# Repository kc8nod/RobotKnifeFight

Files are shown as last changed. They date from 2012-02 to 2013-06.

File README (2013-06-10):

Robot Knife Fight v0.10 (master)

Robot Knife Fight is a game that uses Python 2.7+, Arduino v1.0.3+, OpenCV 2.4.5+, and zbar 0.10 to scan a video source for QR codes for robot positions, if the robot is alive, and the arena's edges.  The position is sent out via an Arduino transmitter using a Virtual Wire 433Mhz Radio to each Arduino robot.  Each robot has a balloon covering it's DEAD symbol that also holds down it's power button.  When it's balloon pops the robot turns off.

The game is simple.  Each robot tries to pop the balloon of the other robots and be the last alive.

We are currently in Beta stages.  Positioning works but could use some optimizations.  The 433Mhz Radio that each Arduino uses to receive the position of itself and the other robots could use review.  The QR scanning with zbar could be set to focus on just the arena area.  Setting zbar to increase the number of scanning passes on certain areas of the image is also possible.

3d_model/                           #Sketchup design files for the robot.
code/arena/                         #Python script that scans the video for QR codes
                                    # and sends commands to the transmitter.
code/example_bot_attack /           #Arduino robot code that drives straight towards
                                    # the nearest living robot.
code/example_bot_patrol/            #Arduino robot code patrols between 4 points.
code/libraries/                     #Libraries you will need to copy to your 
                                    # 'arduino/libraries' folder.
code/rkf_xmit/                      #Arduino code for the transmitter.
code/serial_drivable_bot/           #Arduino robot code that's drivable via serial
                                    # commands (Xbee, Bluetooth, etc.)
code/serial_keyboard_controller/    #Processing script to drive up to 2 bots via
                                    # serial connections.
harware/                            #Shield Schematic for Virtual Wire Radio, servo
                                    # connectors, switch connectors, and a serial
                                    # module (Bluetooth Mate, FTDI pinout).
lasercut/                           #The exported DXF file of the Flat_Pack.skp for
                                    # lasercutting the robot.
qrcodes/                            #PNG files of the QR codes for the arena corners
                                    # (A###-C#), Robot symbols (http://###), and the
                                    # robot death symbols (DEAD###).

We currently suggest print sizes of 5.25"x5.25" for arena corners and 4.25"x4.25" for robot symbols.

Check http://i3detroit.com for events.

https://github.com/SWiT/RobotKnifeFight
https://github.com/kc8nod/RobotKnifeFight

https://github.com/SWiT/RobotFightClubArena

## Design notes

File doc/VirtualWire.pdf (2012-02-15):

February 7, 2012

### 1 of 13

# VirtualWire

Copyright (C) 2008-2011
Mike McCauley

Documentation for the VirtualWire 1.9 communications library for Arduino.

### 1.0 Introduction

Arduino is a low cost microcontroller with Open Source hardware, see http://www.arduino.cc. VirtualWire is a communications library for Arduino that allows multiple Arduino’s to communicate using low-cost RF transmitters and receivers.

The document describes the VirtualWire library and how to install and use it.

You can also find online help and disussion at

http://groups.google.com/group/virtualwire

### 2.0 Overview

VirtualWire is an Arduino library that provides features to send short messages, without addressing, retransmit or acknowledgment, a bit like UDP over wireless, using ASK (amplitude shift keying). Supports a number of inexpensive radio transmitters and receivers. All that is required is transmit data, receive data and (for transmitters, optionally) a PTT transmitter enable.

It is intended to be compatible with the RF Monolithics (www.rfm.com) Virtual Wire protocol, but this has not been tested.

Does not use the Arduino UART. Messages are sent with a training preamble, message length and checksum. Messages are sent with 4-to-6 bit encoding for good DC balance, and a CRC checksum for message integrity.

Overview

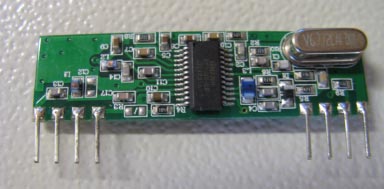
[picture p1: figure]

2 of 13 | VirtualWire

Why not just use the Arduino UART connected directly to the transmitter/receiver? As discussed in the RFM documentation, ASK receivers require a burst of training pulses to synchronize the transmitter and receiver, and also requires good balance between 0s and 1s in the message stream in order to maintain the DC balance of the message. UARTs do not provide these. They work a bit with ASK wireless, but not as well as this code.

2.1 Supported hardware.
A range of communications hardware is supported. The ones listed blow are available in common retail outlets in Australian and other countries for under $10 per unit. Many other modules may also work with this software.

Runs on ATmega8/168 (Arduino Diecimila etc) and ATmega328 and possibly others.

### 2.2 Receivers

- RX-B1 (433.92MHz) (also known as ST-RX04-ASK)
FIGURE 1. | RX-B1

Details at http://www.summitek.com.tw/ST_SPEC/ST-RX04-ASK.pdf

### 2.3 Transmitters:

- TX-C1 (433.92MHz)

Overview

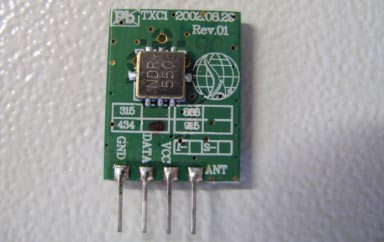
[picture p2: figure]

VirtualWire | 3 of 13
FIGURE 2. | TX-C1

Details at http://www.tato.ind.br/files/TX-C1.pdf

### 2.4 Transceivers:

- DR3100 (433.92MHz)

Downloading and installation

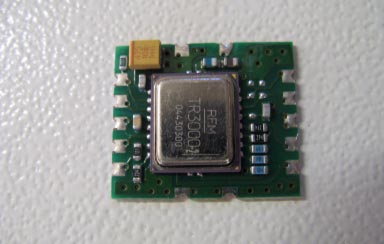
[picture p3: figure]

4 of 13 | VirtualWire
FIGURE 3. | DR3100

Details at http://www.rfmonolithics.com/products/data/dr3100.pdf

### 3.0 Downloading and installation

The latest version of this document is available from

http://www.open.com.au/mikem/arduino/VirtualWire.pdf

Download the VirtualWire distribution from

http://www.open.com.au/mikem/arduino/VirtualWire-1.9.zip

To install, unzip the library into the libraries sub-directory of your Arduino application directory. Then launch the Arduino environment; you should see the library in the Sketch->Import Library menu, and example code in File->Sketchbook->Examples->VirtualWire menu.

### 4.0 Function calls

To use the VirtualWire library, you must have

#include <VirtualWire.h>

At the top of your sketch.

Function calls

VirtualWire | 5 of 13

### 4.1 vw_set_tx_pin

extern void vw_set_tx_pin(uint8_t pin);

Set the digital IO pin to use for transmit data. Defaults to 12.

### 4.2 vw_set_rx_pin

extern void vw_set_rx_pin(uint8_t pin);

Set the digital IO pin to use for receive data. Defaults to 11.

### 4.3 vw_set_ptt_pin

extern void vw_set_ptt_pin(uint8_t pin);

Set the digital IO pin to use to enable the transmitter (press to talk). Defaults to 10. Not all transmitters require PTT. The DR3100 does, but the TX-B1 does not.

### 4.4 vw_set_ptt_inverted

extern void vw_set_ptt_inverted(uint8_t inverted);

By default the PTT pin goes high when the transmitter is enabled. This flag forces it low when the transmitter is enabled. Required for the DR3100.

### 4.5 vw_setup

extern void vw_setup(uint16_t speed);

Initialise the VirtualWire software, to operate at speed bits per second. Call this once in your setup() after any vw_set_* calls. You must call vw_rx_start() after this before you will get any messages.

### 4.6 vw_rx_start

extern void vw_rx_start();

Start the receiver. You must do this before you can receive any messages. When a message is available (good checksum or not), vw_have_message() will return true.

### 4.7 vw_rx_stop

extern void vw_rx_stop();

Stop the receiver. No messages will be received until vw_rx_start() is called again. Saves interrupt processing cycles when you know there will be no messages.

### 4.8 vx_tx_active

extern uint8_t vx_tx_active();

Sample code

6 of 13 | VirtualWire

Return true if the transmitter is active

### 4.9 vw_wait_tx

extern void vw_wait_tx();

Block and wait until the transmitter is idle

### 4.10 vw_wait_rx

xtern void vw_wait_rx();

Block and wait until a message is available from the receiver.

### 4.11 vw_wait_rx_max

extern uint8_t vw_wait_rx_max(unsigned long milliseconds);

Wait at most milliseconds ms for a message to be received. Return true if a message is available.

### 4.12 vw_send

extern uint8_t vw_send(uint8_t* buf, uint8_t len);

Send a message with the given length. Returns almost immediately, and the message will be sent at the right timing by interrupts. Returns true if the message was accepted for transmission. Returns false if the message is too long (>VW_MAX_PAYLOAD).

### 4.13 vw_have_message

extern uint8_t vw_have_message();

Returns true if an unread message is available from the receiver.

### 4.14 vw_get_message

extern uint8_t vw_get_message(uint8_t* buf, uint8_t* len);

If a message is available (good checksum or not), copies up to *len octets to buf. Returns true if there was a message and the checksum was good.

### 5.0 Sample code

The following samples are available as examples in the VirtualWire distribution.

### 5.1 transmitter

A simplex (one-way) transmitter. Sends a short message every 400 ms. Test this with the receiver below.

Sample code

VirtualWire | 7 of 13

#include <VirtualWire.h>

void setup()
{
vw_setup(2000); // Bits per sec }
void loop()
{
const char *msg = "hello"; vw_send((uint8_t *)msg, strlen(msg)); delay(400);
}

### 5.2 receiver

A simplex (one-way) receiver. Waits for a message and dumps it contents. Test this with transmitter above.

#include <VirtualWire.h>

void setup()
{
Serial.begin(9600);
Serial.println("setup");
vw_setup(2000); // Bits per sec
vw_rx_start(); // Start the receiver PLL running }
void loop()
{
uint8_t buf[VW_MAX_MESSAGE_LEN];
uint8_t buflen = VW_MAX_MESSAGE_LEN;
if (vw_get_message(buf, &buflen)) // Non-blocking
{
int i;
// Message with a good checksum received, dump HEX Serial.print("Got: ");
for (i = 0; i < buflen; i++)
{
Serial.print(buf[i], HEX); Serial.print(" ");
}
Serial.println("");
}
}

### 5.3 client

Implements a simple wireless client for DR3100. Sends a message to another Arduino running the server code below and waits for a reply.

#include <VirtualWire.h>

void setup()
{
Serial.begin(9600);// Debugging only Serial.println("setup");
vw_set_ptt_inverted(true); // Required for DR3100

Sample code

8 of 13 | VirtualWire

vw_setup(2000); // Bits per sec
vw_rx_start(); | // Start the receiver PLL running
}
void loop()
{
const char *msg = "hello";
uint8_t buf[VW_MAX_MESSAGE_LEN];
uint8_t buflen = VW_MAX_MESSAGE_LEN; vw_send((uint8_t *)msg, strlen(msg));
vw_wait_tx(); // Wait until the whole message is gone Serial.println("Sent");
// Wait at most 400ms for a reply
if (vw_wait_rx_max(400))
{
if (vw_get_message(buf, &buflen)) // Non-blocking
{
int i;
// Message with a good checksum received, dump it. Serial.print("Got reply: ");
for (i = 0; i < buflen; i++)
{
Serial.print(buf[i], HEX); Serial.print(" ");
}
Serial.println("");
}
}
else
Serial.println("Timout");
}

### 5.4 server

Implements a simple wireless server for DR3100. Waits for a message from another Arduino running the client code above and sends a reply.

#include <VirtualWire.h>

void setup()
{
Serial.begin(9600);// Debugging only Serial.println("setup");
vw_set_ptt_inverted(true); // Required for DR3100 vw_setup(2000); // Bits per sec
vw_rx_start(); | // Start the receiver PLL running
}
void loop()
{
const char *msg = "hello";
uint8_t buf[VW_MAX_MESSAGE_LEN]; uint8_t buflen = VW_MAX_MESSAGE_LEN;

// Wait for a message
vw_wait_rx();
if (vw_get_message(buf, &buflen)) // Non-blocking

Implementation Details

VirtualWire | 9 of 13

{
int i;
const char *msg = "goodbye";
// Message with a good checksum received, dump it. Serial.print("Got: ");
for (i = 0; i < buflen; i++)
{
Serial.print(buf[i], HEX); Serial.print(" ");
}
Serial.println("");
// Send a reply
vw_send((uint8_t *)msg, strlen(msg)); }
}

### 6.0 Implementation Details

Messages of up to VW_MAX_PAYLOAD (27) bytes can be sent

Each message is transmitted as:
- 36 bit training preamble consisting of 0-1 bit pairs
- 12 bit start symbol 0xb38
- 1 byte of message length byte count (4 to 30), count includes byte count and FCS bytes
- n message bytes, maximum n is VW_MAX_PAYLOAD (27)
- 2 bytes FCS, sent low byte-hi byte

Everything after the start symbol is encoded 4 to 6 bits, Therefore a byte in the message is encoded as 2x6 bit symbols, sent hi nybble, low nybble. Each symbol is sent LSBit first.

The Arduino Diecimila clock rate is 16MHz => 62.5ns/cycle.

For an RF bit rate of 2000 bps, need 500microsec bit period.

The ramp requires 8 samples per bit period, so need 62.5microsec per sample => interrupt tick is 62.5microsec.

The maximum packet length consists of

(6 + 2 + VW_MAX_MESSAGE_LEN*2) * 6 = 408 bits = 0.204 secs (at 2000 bps).

where VW_MAX_MESSAGE_LEN is VW_MAX_PAYLOAD + 3 (= 30).

The code consists of an ISR interrupt handler. Most of the work is done in the interrupt handler for both transmit and receive, but some is done from the user level. Expensive functions like CRC computations are always done in the user level.

Performance

10 of 13 | VirtualWire

### 7.0 Performance

Unit tests show that the receiver PLL can stand up to 1 sample in 11 being inverted by noise without ill effect.

Testing with TX-C1, RX-B1, 5 byte message, 17cm antenna, no ground plane, 1m above ground, free space

At 10000 bps the transmitter does not operate correctly (ISR running too frequently at 80000/sec?)

At 9000 bps, asymmetries in the receiver prevent reliable communications at any distance

At 7000bps, Range about 90m

At 5000bps, Range about 100m

At 2000bps, Range over 150m

At 1000bps, Range over 150m

As suggested by RFM documentation, near the limits of range, reception is strongly influenced by the presence of a human body in the signal line, and by module orientation.

Throughout the range there are nulls and strong points due to multipath reflection. So... your mileage may vary.

Similar performance figures were found for DR3100. 9000bps worked.

Arduino and TX-C1 transmitter draws 27mA at 9V.

Arduino and RX-B1 receiver draws 31mA at 9V.

Arduino and DR3100 receiver draws 28mA at 9V.

### 8.0 Connections

Note that the IO pins can be changed from their defaults (as shown here) to any suitable IO pins using the vw_set_*_pin() calls.

Connections

VirtualWire | 11 of 13

### 8.1 RX-B1 receiver

FIGURE 4. | Wiring for RX-B1 receiver

### 8.2 TX-C1 transmitter

FIGURE 5. | Wiring for TX-C1 transmitter

Arduino
RX-B1
11 | Data
5V | Vcc
Gnd | Gnd

Ant

Arduino
TX-C1 12 | Data
3V3 | Vcc
Gnd | Gnd

Ant

Connections

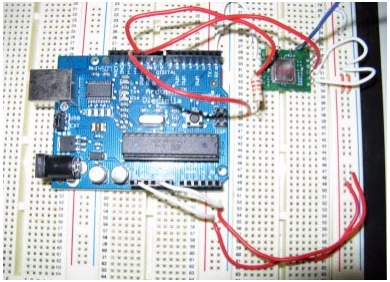
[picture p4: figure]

12 of 13 | VirtualWire

### 8.3 DR3100 transceiver

FIGURE 6. | Wiring for DR3100
FIGURE 7. | DR3100 connections on breadboard
Arduino | DR3100
11
Gnd | 10

13

4 Rx Data
RFIO
RF Gnd | 14
12 | 5 | Tx In
3V3 | 9
| 12
1

Vcc
Ctr0
AGC

Gnd

12k
10 | 11 | Ctr1

Copyright and License

VirtualWire | 13 of 13

Connections shown for no AGC, 1mW power out, 2400bps. Note the 12k resistor in series with Tx In to control the power output If you want to use higher data rates, need a resistor from pin 8 of the DR3100 to ground (see RFM documentation for more details).

If you want to use AGC, need a capacitor from pin 1 of the DR3100 to ground (see RFM documentation for more details).

The DR3100 module is supplied without any connection pins, only surface mount style pads. You will need to solder pins onto the module if you wish to use it in a breadboard.

### 9.0 Copyright and License

This software is Copyright (C) 2008 Mike McCauley. Use is subject to license conditions. The main licensing options available are GPL V2 or Commercial:

### 9.1 Open Source Licensing GPL V2

This is the appropriate option if you want to share the source code of your application with everyone you distribute it to, and you also want to give them the right to share who uses it. If you wish to use this software under Open Source Licensing, you must contribute all your source code to the open source community in accordance with the GPL Version 2 when your application is distributed. See http://www.gnu.org/copyleft/gpl.html

### 9.2 Commercial Licensing

This is the appropriate option if you are creating proprietary applications and you are not prepared to distribute and share the source code of your application. Contact info@open.com.au for details.

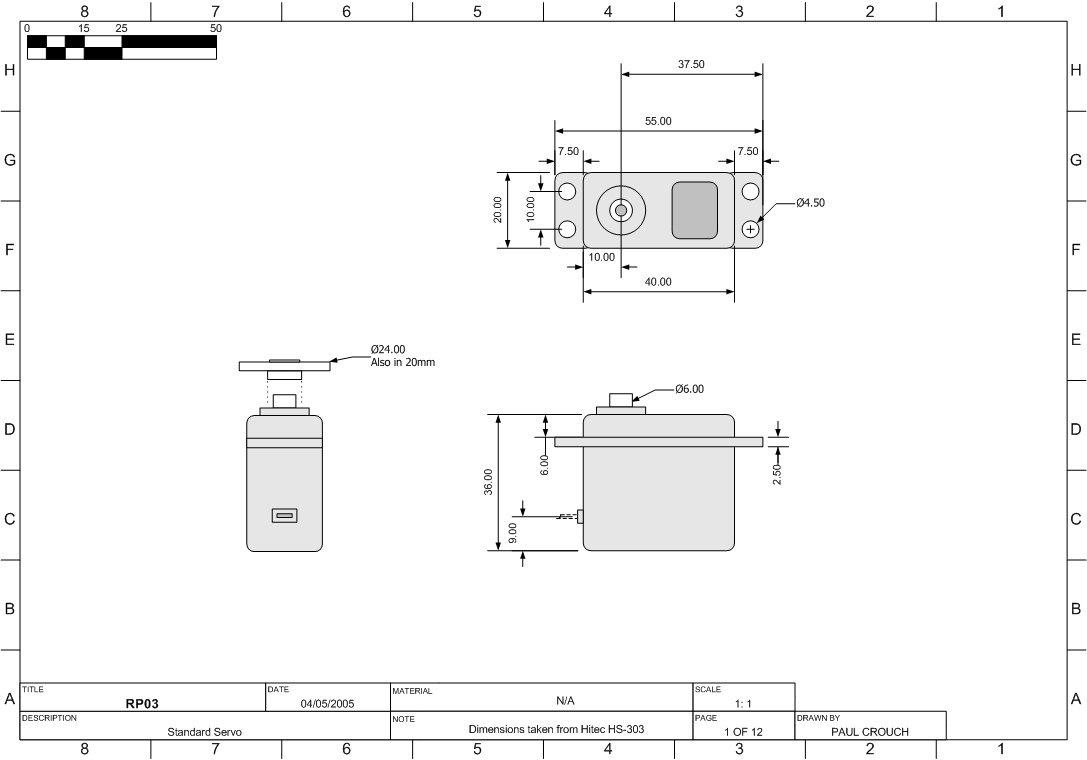
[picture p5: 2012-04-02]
doc/StandardServoDimensions.jpg

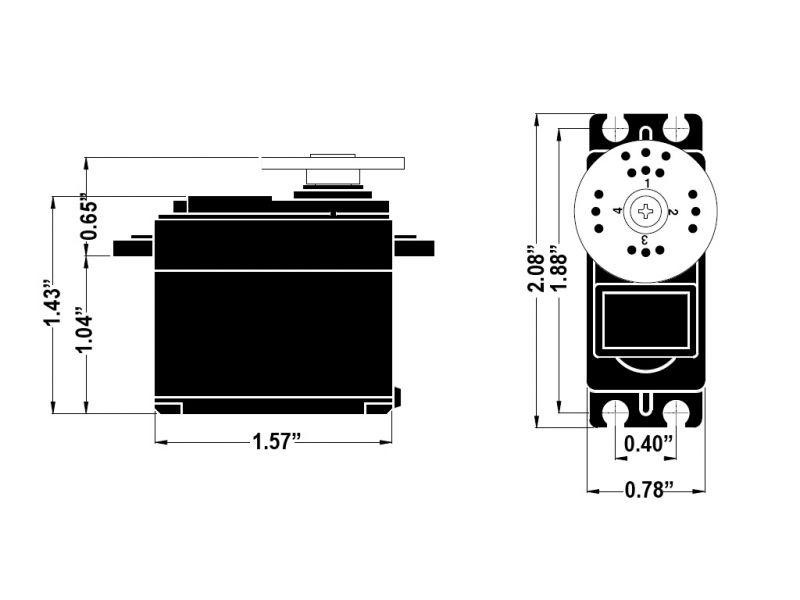
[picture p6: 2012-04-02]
doc/hitec hs-311.jpg

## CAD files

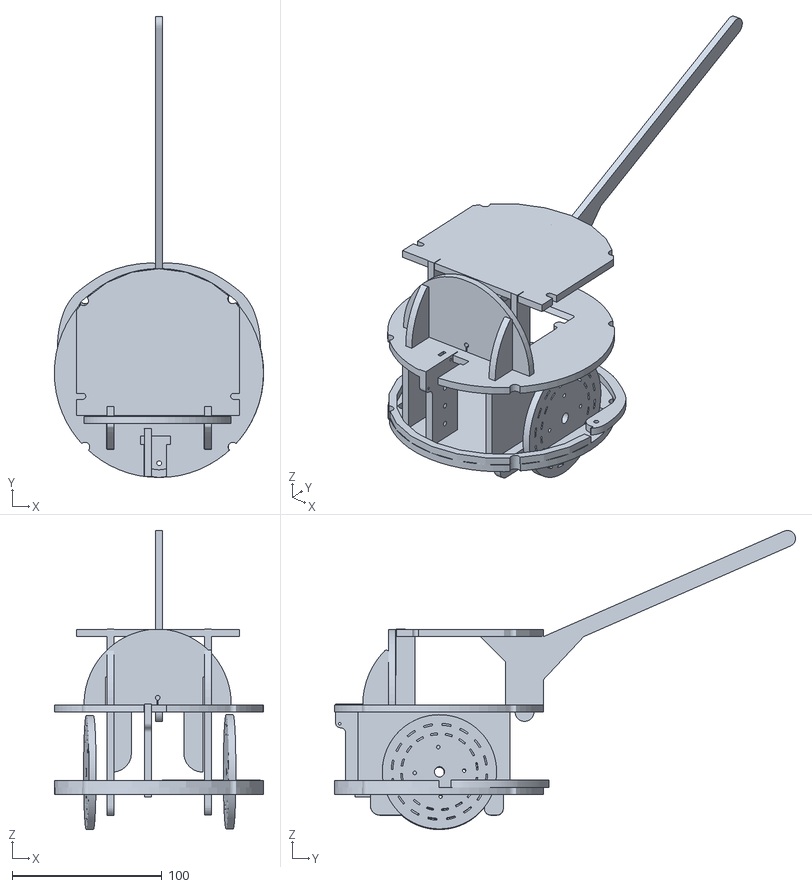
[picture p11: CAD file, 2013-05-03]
3d_model/Assembled_Bot.stl
139.8 x 307.9 x 199.8

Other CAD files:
lasercut/i3b_lasercut.dxf
3d_model/4 x AA batteries in holder.skp
3d_model/4AA_battery.skp
3d_model/Arduino Duemilanove.skp
3d_model/Assembled_Bot.skp
3d_model/Flat_Pack.skp
3d_model/arm.skp
3d_model/bottom_plate.skp
3d_model/bump_guard.skp
3d_model/bump_switch.skp
3d_model/bumper.skp
3d_model/crown.skp
3d_model/killswitch_bracket.skp
3d_model/microswitch.skp
3d_model/servo.skp
3d_model/servo2.skp
3d_model/side.skp
3d_model/symbol_plate.skp
3d_model/top_plate.skp
3d_model/vertical.skp
3d_model/wheel.skp

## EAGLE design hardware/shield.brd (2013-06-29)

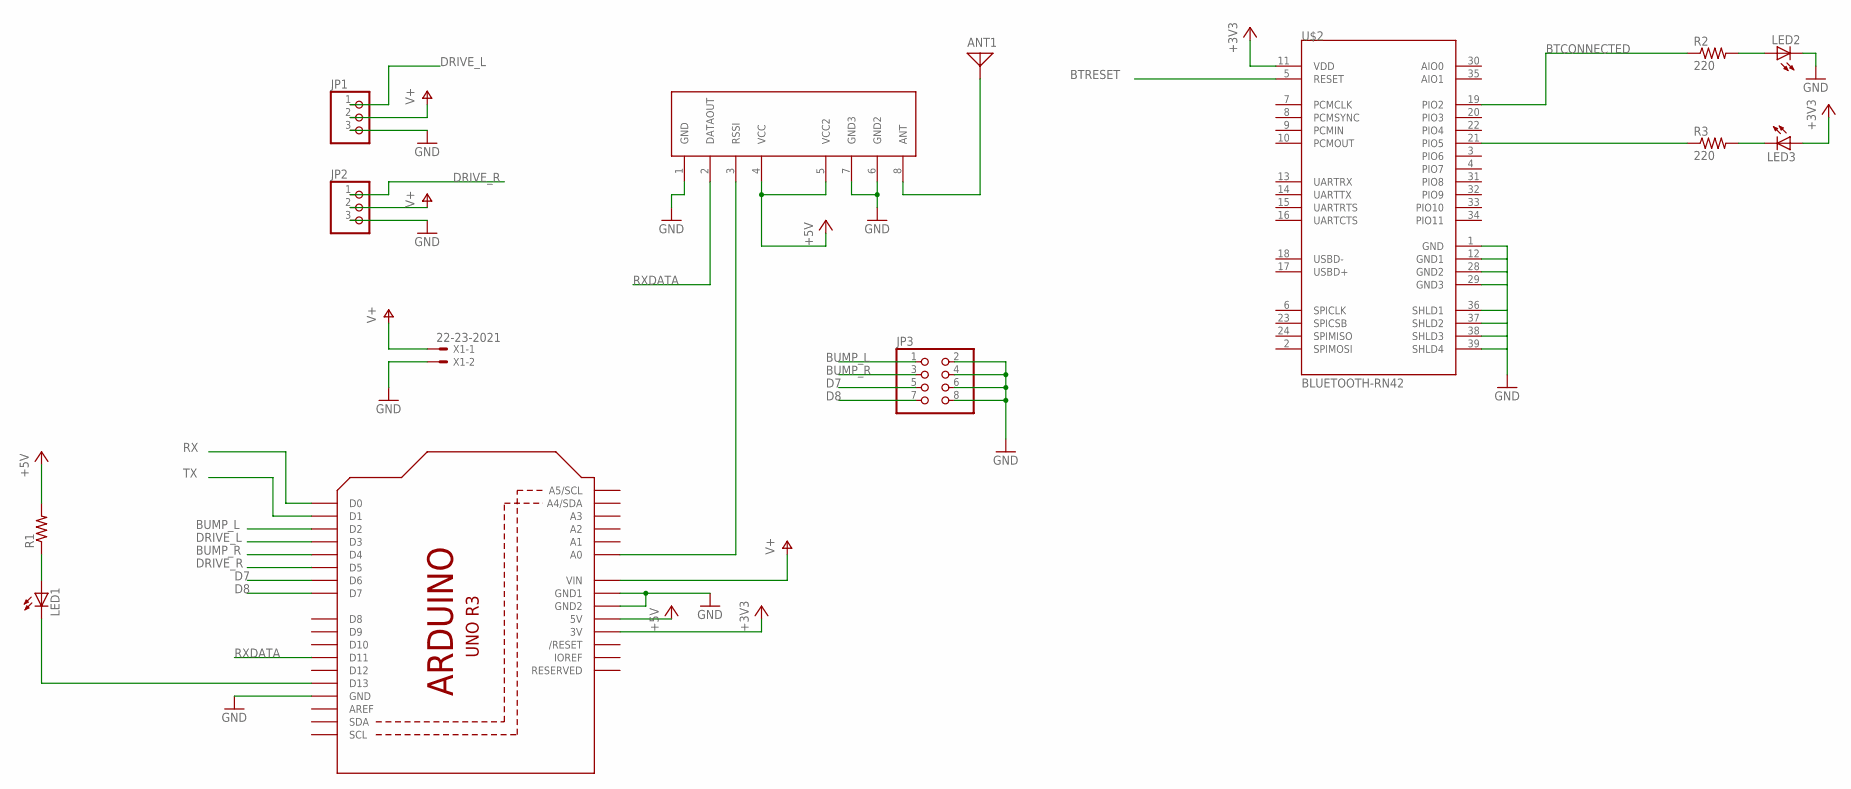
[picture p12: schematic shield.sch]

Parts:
ANT1: ANTENNA; PAD-01
JP1, JP2: PINHD-1X3; 1X03
JP3: PINHD-2X4; 2X04
LED1, LED2, LED3: LED3MM
R1: R-US_R0805; R0805
R2, R3: 220; R0805
U1: ARDUINOR3-DIMENSION; ARDUINOR3
U$1: RWS371; RWS-371
U$2: BLUETOOTH-RN42; RN42
X1: 22-23-2021

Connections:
+3V3: LED3.A, U1.3V, U$2.11 (VDD)
+5V: R1.2, U1.5V, U$1.4 (VCC), U$1.5 (VCC2)
BTCONNECTED: R2.1, U$2.19 (PIO2)
BTRESET: U$2.5 (RESET)
BUMP_L: JP3.1, U1.D2
BUMP_R: JP3.3, U1.D4
D7: JP3.5, U1.D6
D8: JP3.7, U1.D7
DRIVE_L: JP1.1, U1.D3
DRIVE_R: JP2.1, U1.D5
GND: JP1.3, JP2.3, JP3.2, JP3.4, JP3.6, JP3.8, LED2.K (C), U1.GND, U1.GND1, U1.GND2, U$1.1 (GND), U$1.6 (GND2), U$1.7 (GND3), U$2.1 (GND), U$2.12 (GND1), U$2.28 (GND2), U$2.29 (GND3), U$2.36 (SHLD1), U$2.37 (SHLD2), U$2.38 (SHLD3), U$2.39 (SHLD4), X1.2
unnamed: U1.A0, U$1.3 (RSSI)
unnamed: LED1.A, R1.1
unnamed: LED1.K (C), U1.D13
unnamed: ANT1.1, U$1.8 (ANT)
unnamed: LED2.A, R2.2
unnamed: LED3.K (C), R3.2
unnamed: R3.1, U$2.21 (PIO5)
RX: U1.D0
RXDATA: U1.D11, U$1.2 (DATAOUT)
TX: U1.D1
V+: JP1.2, JP2.2, U1.VIN, X1.1

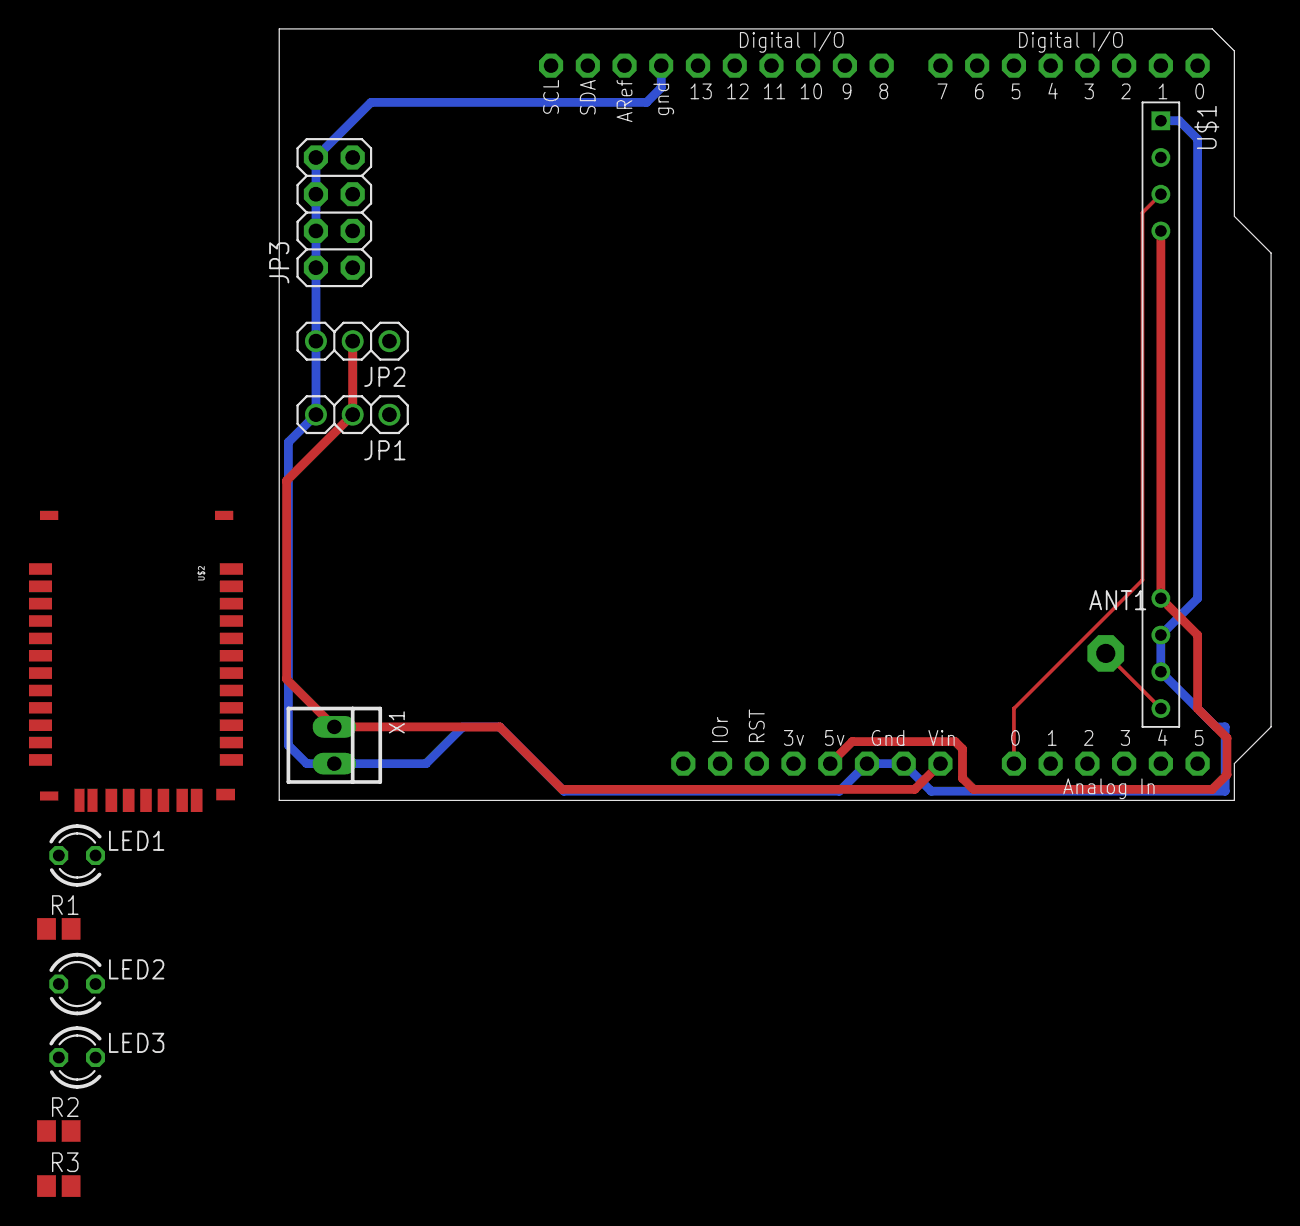
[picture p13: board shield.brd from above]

Board: 2 copper layers, 68.6 x 53.3 mm, 14 parts (0 on the bottom side), 19 nets.

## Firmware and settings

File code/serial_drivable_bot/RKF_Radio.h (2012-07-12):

#include <Arduino.h>
#include <Print.h>

#define DEFAULT_BAUD_RATE  4800
#define DEFAULT_RX_PIN       11

class RKF_Position
{
  public:
  
  byte x;
  byte y;
  byte heading : 4;
  byte valid   : 1;
 
  int distance(RKF_Position&);
  double bearing(RKF_Position&);
};


class RKF_Packet 
{
  public:
  
  union
  {
    byte data[27];
    
    struct
    {
      byte message;
      byte reserved0;
      byte reserved1;
    
      RKF_Position robot[8];
    }; 
  };
};

class RKF_Radio : public Printable
{
  public:
  
  RKF_Packet packet;

  int start();
  int start(int);
  int start(int, int);
  int recv();
  size_t printTo(Print&) const;
};

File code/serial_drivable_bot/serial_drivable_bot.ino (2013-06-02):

#include "bot_id.h"
#include <ServoTimer2.h>
#include <VirtualWire.h>
#include "pin_defs.h"
#include "RKF_Radio.h"

unsigned long now = 0;
unsigned long timeLastServoUp = 0;
unsigned long timeLastSerialInput = 0;

ServoTimer2 LeftDrive, RightDrive;

boolean bump_L = false;
boolean bump_R = false;

#define LEFT_FWD 2000
#define LEFT_STOP 1500
#define LEFT_REV 1000

#define RIGHT_FWD 1000
#define RIGHT_STOP 1500
#define RIGHT_REV 2000

unsigned int speed_L = LEFT_STOP;
unsigned int speed_R = RIGHT_STOP;

RKF_Radio radio;
unsigned long timeLastMessage = 0;
unsigned int message_count = 0;
extern "C" { uint8_t vw_rx_active; };

String serialInputString = "";  // a string to hold incoming data


void setup() {
  LeftDrive.attach(LEFT_DRIVE_PIN);
  RightDrive.attach(RIGHT_DRIVE_PIN);
  
  pinMode(BUMP_SWITCH_RIGHT_PIN, INPUT);
  pinMode(BUMP_SWITCH_LEFT_PIN, INPUT);
  pinMode(DEFAULT_RX_PIN, INPUT);
  pinMode(STATUS_LED_PIN, OUTPUT);
  
  LeftDrive.write(LEFT_STOP);
  RightDrive.write(RIGHT_STOP);
  
  radio.start();
  
  serialInputString.reserve(16);
  Serial.begin(115200);
  Serial.println("{\"msg\":\"bt_drivable_bot reset\"}");
}


void loop() {
  
  now = millis();
  
  if(processSerialInput()){
    timeLastSerialInput = now;
  }
   //if no new data for 5 seconds, stop.
  if(now - timeLastSerialInput > 5000){
    speed_L = LEFT_STOP;
    speed_R = RIGHT_STOP;
  }
  
  //Read Bump Switches
  bump_R = digitalRead(BUMP_SWITCH_RIGHT_PIN);
  if(!bump_R){
    outputStatus();
  }
  bump_L = digitalRead(BUMP_SWITCH_LEFT_PIN);
  if(!bump_L){
    outputStatus();
  }
  
  //Update Servo positions  
  if(now - timeLastServoUp > 15){  //limit servo updating to every 15ms at most
    LeftDrive.write(speed_L);
    RightDrive.write(speed_R);
    timeLastServoUp = now;
  }
  
}
//end loop()


/*
  outputStatus
output important variables to the Serial port
------------------------------------------------------------------------------*/
void outputStatus(){
  Serial.print("{");
  Serial.print("\"now\":");
  Serial.print(now);
  Serial.print(", \"speed_L\":");
  Serial.print(speed_L);
  Serial.print(", \"speed_R\":");
  Serial.print(speed_R);
  Serial.print(", \"bump_L\":");
  Serial.print(bump_L);
  Serial.print(", \"bump_R\":");
  Serial.print(bump_R);
  //Serial.print(", vw_rx_active:");
  //Serial.print(vw_rx_active);
  //Serial.print(", radio_count:");
  //Serial.println(message_count);
  //Serial.println(radio);
  Serial.print("}");
  Serial.println();
}


void setLeftSpeed(boolean forward, int throttle){
  if(0 <= throttle && throttle <= 100){
    int x = (forward) ? LEFT_FWD : LEFT_REV;
    speed_L = (x - LEFT_STOP) * float(throttle)/100 + LEFT_STOP;
  }else{
    error_bad_param(throttle);
  }
}


void setRightSpeed(boolean forward, int throttle){
  if(0 <= throttle && throttle <= 100){
    int x = (forward) ? RIGHT_FWD : RIGHT_REV;
    speed_R = (x - RIGHT_STOP) * float(throttle)/100 + RIGHT_STOP;
  }else{
    error_bad_param(throttle);
  }
}

void error_bad_param(int param){
  Serial.print("{\"msg\":\"ERROR BAD PARAM ");
  Serial.print(param);
  Serial.println("\"}");
}

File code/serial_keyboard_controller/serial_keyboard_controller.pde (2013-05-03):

 import processing.serial.*; 
 
 int typedKeyCode = 0; 
 
 float boxX;
 float boxY;
 int boxSize;
 int boxMargin;
 
 String[] listOfPorts;

 final int STOP_ALL_BOTS = int(' '); 
 boolean stopAll = false;
 
 boolean playersSelected = false;
 int numberOfPlayers = 0;
 final int maxPlayers = 2;
 
 Player[] player = new Player[maxPlayers];
  
 float button1X, button1Y, button2X, button2Y, throttleX, throttleY;
 
 void setup()  {
   size(400, (200*maxPlayers));
   boxX = 100;
   boxY = 100;
   button1X = 275;
   button1Y = 100;
   button2X = 340;
   button2Y = 100;
   throttleX = 200;
   throttleY = 100;
   rectMode(RADIUS); 
   
   for(int i=0; i<maxPlayers; i++){
     player[i] = new Player(this, i+1);
   }
 }
 
 
 void draw(){
   background(0);
   
   //Select the number of Players
   if(!selectPlayers()){
     return;
   }
   
   for(int i=0; i<numberOfPlayers; i++){
     drawPlayerLabel(i);
     
     //If not connected, select an available Serial Port and connect to it.
     if(!player[i].serialPortConnected()){
       return;
     }
     
     //Get any new serial data and print it.
     player[i].printSerialData();
     
     // Draw the shapes
     drawCentered(i);
     drawUp(i);
     drawDown(i);
     drawRight(i);
     drawLeft(i);
     drawButton1(i);
     drawButton2(i);
     drawThrottle(i);
     drawPort(i);
     
     //Send command to port(s)
     player[i].sendCommandToPort();
   }
 } 
 
 
 boolean selectPlayers(){
   if(playersSelected == false){
     text("Select Number of Players: [1-"+maxPlayers+"]", 10, 15);
     if(typedKeyCode > 0){
       println("Select Number of Players: [1-"+maxPlayers+"]");
       numberOfPlayers = int(key)-48;
       if(1 <= numberOfPlayers && numberOfPlayers <= maxPlayers){
         println(numberOfPlayers + " Players");
         playersSelected = true;
       }
       typedKeyCode = 0; //reset typed keyCode
     }
   }
   return playersSelected;
 }
 
 
  void keyPressed() {
   if(keyCode > 0){
     println("pressed: "+ keyCode +" = '"+ key +"'");
     for(int i=0; i<numberOfPlayers; i++){
       if(keyCode == player[i].UP_KEY){
         player[i].up = true;
         
       }else if(keyCode == player[i].LEFT_KEY){
         player[i].left = true;
         
       }else if(keyCode == player[i].DOWN_KEY){
         player[i].down = true;
         
       }else if(keyCode == player[i].RIGHT_KEY){
         player[i].right = true;
         
       }else if(keyCode == player[i].B2_KEY){
         player[i].speed += 2;
         player[i].speed = constrain(player[i].speed, 0, 100);
         player[i].button2 = true;
         
       }else if(keyCode == player[i].B1_KEY){
         player[i].speed -= 2;
         player[i].speed = constrain(player[i].speed, 0, 100);
         player[i].button1 = true;
         
       }else if(keyCode == STOP_ALL_BOTS){
         player[i].up = player[i].down = player[i].left = player[i].right = false;
         stopAll = true;
         player[i].speed = 0;  
       }
     }
   }
 }
 
 
 void keyReleased() {
   if(keyCode > 0){
     println("released: "+ keyCode +" = '"+ key +"'");
     for(int i=0; i<numberOfPlayers; i++){
       if(keyCode == player[i].UP_KEY){
         player[i].up = false;
         
       }else if(keyCode == player[i].LEFT_KEY){
         player[i].left = false;
           
       }else if(keyCode == player[i].DOWN_KEY){
         player[i].down = false;
           
       }else if(keyCode == player[i].RIGHT_KEY){
         player[i].right = false;
           
       }else if(keyCode == player[i].B2_KEY){
         player[i].button2 = false;
         
       }else if(keyCode == player[i].B1_KEY){
         player[i].button1 = false;
         
       }else if(keyCode == STOP_ALL_BOTS){
         stopAll = false;
         player[i].speed = 0;  
       }
     }
     typedKeyCode = keyCode; 
   }
 }

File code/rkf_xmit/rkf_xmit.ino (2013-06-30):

#include <SerialCommand.h>
#include <VirtualWire.h>
#include "rkf_packet.h"

#define LED_PIN 13
#define TX_PIN  12

uint16_t tx_msg_count;

SerialCommand sCmd;     // The SerialCommand object

boolean tx_enabled_flag = false;
unsigned long next_xmit_time = 0; //time of the next transmit
unsigned long time_xmit_complete = 0;
RKF_Packet send_pkt_buffer;
int send_data_len;

int xmit_period  = 100;
int xmit_min     = 50;
int baud_rate    = 4800;

void (*softReset) (void) = 0; // soft reset function


void setup() {
    
  memset((void*)&send_pkt_buffer, 0, sizeof(send_pkt_buffer));

  pinMode(LED_PIN, OUTPUT);      // Configure the onboard LED for output
  
  // Setup callbacks for SerialCommand commands
  sCmd.addCommand("pos",   set_position);  // send position report for a robot
  sCmd.addCommand("start", start_tx);      // start transmitting
  sCmd.addCommand("stop", stop_tx);      // start transmitting
  sCmd.addCommand("reset", resetXmit);
  sCmd.addCommand("data",  send_raw_data);
  sCmd.addCommand("?",   send_printPacket);
  sCmd.setDefaultHandler(unrecognized);      // Handler for command that isn't defined
  
  Serial.begin(115200);
  Serial.println("rkf_xmit: reset");
  printHelp();
}


void loop()
{
  sCmd.readSerial();     // process serial commands
  
  if(tx_enabled_flag){
    unsigned long now = millis();
    if(now > next_xmit_time){
      next_xmit_time = now + xmit_period;
      time_xmit_complete = now + xmit_min;
      
      // transmit the packet

      vw_wait_tx();
      digitalWrite(LED_PIN, HIGH);
      vw_send((uint8_t*) &send_pkt_buffer, send_data_len);      
  
      Serial.print("TX:");
      Serial.print(tx_msg_count++);
      Serial.print(' ');
      printPacket(send_pkt_buffer);
    }
    
    vw_wait_tx();
    digitalWrite(LED_PIN, LOW);
    
    
  }else{
    digitalWrite(LED_PIN, LOW);
  }
}


void resetXmit(){
  Serial.println("RESET");
  delay(500);
  softReset();
}

void set_position()
{
  byte index;
  byte x_pos;
  byte y_pos;
  byte heading;
  byte alive;
  byte fresh;
  
  RKF_Position * pRobot;
  
  index   = byte(atoi(sCmd.next()));
  x_pos   = byte(atoi(sCmd.next()));
  y_pos   = byte(atoi(sCmd.next()));
  heading = byte(atoi(sCmd.next()));
  alive   = byte(atoi(sCmd.next()));
  fresh   = byte(atoi(sCmd.next()));
  
  
  pRobot = &send_pkt_buffer.robot[index];
  
  pRobot->x       = x_pos;
  pRobot->y       = y_pos;
  pRobot->heading = heading;
  pRobot->alive   = alive;
  pRobot->fresh   = fresh;
  
  send_data_len = sizeof(send_pkt_buffer);

  Serial.print("SET POSITION: ");
  printPacket(send_pkt_buffer);
  
}


void send_raw_data()
{
  Serial.print("SEND RAW: ");
  char* arg;
  uint8_t* ptr = (uint8_t*)&send_pkt_buffer;
  send_data_len = 0;
  
  while(1)
  {
    arg = sCmd.next();
    if(arg == NULL) break;
   
    *ptr = byte(atoi(arg));
    ptr++;
   
    send_data_len++;
  }
}


void start_tx()
{
  char * arg;
  arg = sCmd.next();
  if(arg != NULL){
    xmit_period = atoi(arg);
  }
  
  arg = sCmd.next();
  if(arg != NULL){
    baud_rate = atoi(arg);
  }
  
  vw_set_tx_pin(TX_PIN);
  vw_setup(baud_rate);

  send_data_len = sizeof(send_pkt_buffer);
  tx_enabled_flag = true;
  
  Serial.print("START: xmit_period=");
  Serial.print(xmit_period);
  Serial.print("ms baud=");
  Serial.print(baud_rate);
  Serial.println("bps");
}


void stop_tx(){
  tx_enabled_flag = false;
  Serial.println("STOP ");
}


// This gets set as the default handler, and gets called when no other command matches.
void unrecognized(const char *command) {
  Serial.print("INVALID COMMAND: ");
  Serial.println(command);
}


void printPacket(RKF_Packet &pkt)
{
  //Serial.print("command type: ");
  //Serial.println(pkt.command, HEX);
  for (int idx = 0; idx < RKF_MAX_BOTS; idx++)
  {
    if(idx>0){Serial.print(" ");}
    Serial.print('(');
    Serial.print(pkt.robot[idx].x);
    Serial.print(',');
    Serial.print(pkt.robot[idx].y);
    Serial.print(',');
    Serial.print(pkt.robot[idx].heading);
    Serial.print(',');
    Serial.print(pkt.robot[idx].alive);
    Serial.print(',');
    Serial.print(pkt.robot[idx].fresh);
    Serial.print(')');
  }
  Serial.print('\n');
}


/*
  printHelp
output the help menu to the Serial port
------------------------------------------------------------------------------*/
void printHelp(){
  Serial.println("Help Menu:");
  Serial.println("----------------");
  Serial.println("start [XMIT_PERIOD] [BAUD_RATE]");
  Serial.println("stop");
  Serial.println("pos ROBOT_NUM X Y HEADING VALID ALIVE");
  Serial.println("reset");
  Serial.println("data BYTE0 [BYTE1] ... [BYTE13]");
  Serial.println("? - display packet buffer");
  Serial.println("----------------");
}

void send_printPacket(){
  Serial.print('?: ');
  printPacket(send_pkt_buffer);
}

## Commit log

2012-02-14 add v1.3 files
    [4 x AA batteries in holder.skp, 4AA_battery.skp, Arduino Duemilanove.skp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]
2012-02-14 shuffle files
    [4 x AA batteries in holder.skp, 4AA_battery.skp, Arduino Duemilanove.skp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]
2012-03-06 updated sketchup models. added new bottom plate to lasercut dxf
    [bottom_plate.dxf, bottom_plate.skp, bumper.skp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]
2012-03-06 added bumpers to lasercut dxf. crown is missing.
    [bumper.dxf, i3b_lasercut.dxf]
2012-03-29 narrowed up the vertical bits. re-kajiggered the bumpers to be smaller and overlap the bottom plate.
    [bottom_plate.skp, bumper.skp, vertical.skp]
2012-04-02 lower profile bumper. narrower vertical members.
    [bottom_plate.dxf, bumper.dxf, bumper.skp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]
2012-04-02 bumpers, verticals and crown all back in
    [i3b_lasercut.dxf]
2012-04-02 add registration holes
    [i3b_lasercut.dxf]
2012-04-02 square up orientation
    [vertical.skp]
2012-06-18 started calibration for arena
2012-07-10 optimized radio settings and code for bot and transmitter. Redefined pins and servo values for latest bot design.
2012-07-12 create camera calibration script. still needs debugging
2012-07-17 fixed the camera -> arena transform and calibration script
2012-07-17 forgot to read config in send_pos and camera_test
2012-07-18 fixed calibrate almost...
2012-07-26 almost there, some numbers are going negative when converting from camera to arena
2012-07-27 fixed calibrate.py defaults. attempting to fix coordinates
2012-08-02 better servo timing, serial baud compatible with BT Mate
2012-08-03 fixed bot thought process, better comments reset stop position to 1500ms for ServoTimer2 removed setup blink
    [output_functions.ino]
2012-08-10 fixing calibration, not done yet
2012-08-12 calibate now asks for camera resolution
2012-09-17 Arduino local echo serial test scipt, Processing keyboard controller.
2012-09-18 improving steering. starting to anyways.
2012-09-20 vastly improved steering
2012-09-20 throttle works.
2012-09-23 Draws Keys on top of buttons. removed boxSize variable, no need to scale interface. Simplified positioning math. Updated wiimote script
2012-10-06 removed extra holes. tweaked ballon key hole and tab length on crown. flatted rest on side for symbol plate. added arm, symbol plate, and bump guard.
    [arm.skp, bottom_plate.skp, bump_guard.skp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]
2012-10-06 fixed symbol plate. removed excess/old files
    [bottom_plate.dxf, bumper.dxf, side.dxf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]
2012-10-06 Assembled bot,fixed bump guard.
    [Assembled_Bot.skp, bump_guard.skp]
2012-10-18 tabs connecting symbol plate and sides. Flat Pack
    [Assembled_Bot.skp, Flat_Pack.skp, crown.skp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]
2013-02-25 create shield schematic. partial layout.
    [shield.brd, shield.sch]
2013-04-09 add .stl file to try out the github renderer
    [Assembled_Bot.stl]
2013-04-22 finally figured out how to focus the camera
2013-06-03 arena location, reset arena, toggle bot dead/alive, draw statuses
    [rfc_qr_arena.py]
2013-06-03 starting to use arduino transmitter
2013-06-13 origin moved some bot code works, other bots broken
    [example_bot_attack.ino, example_bot_patrol.ino, rfc_qr_arena.py]
2013-06-29 add bluetoothdevice to schematic
    [shield.brd, shield.sch]
2013-06-29 improved attack bot, arena position buggy after switch to Quadrant I notation
    [RKF_Radio.h, example_bot_attack.ino, output_functions.ino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]
2013-06-29 moved rfc_qr_arena.py for conveinence. removed runaway bot since it didn't work.
    [RKF_Radio.h, output_functions.ino, pin_defs.h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]
